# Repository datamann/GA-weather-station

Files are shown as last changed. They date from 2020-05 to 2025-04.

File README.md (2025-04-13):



# Google Assistant based weather station
All documentation about this project is found here:
https://sbsivertsen.atlassian.net/wiki/x/cAPNNg

This project consist of several subprojects:
* Remote Sensors
    - PCB project found here: https://easyeda.com/sbsivertsen/attiny84radiotransmitter
* Base Station
* Cloud Storage
* Google Assistant
* Android & IOS App

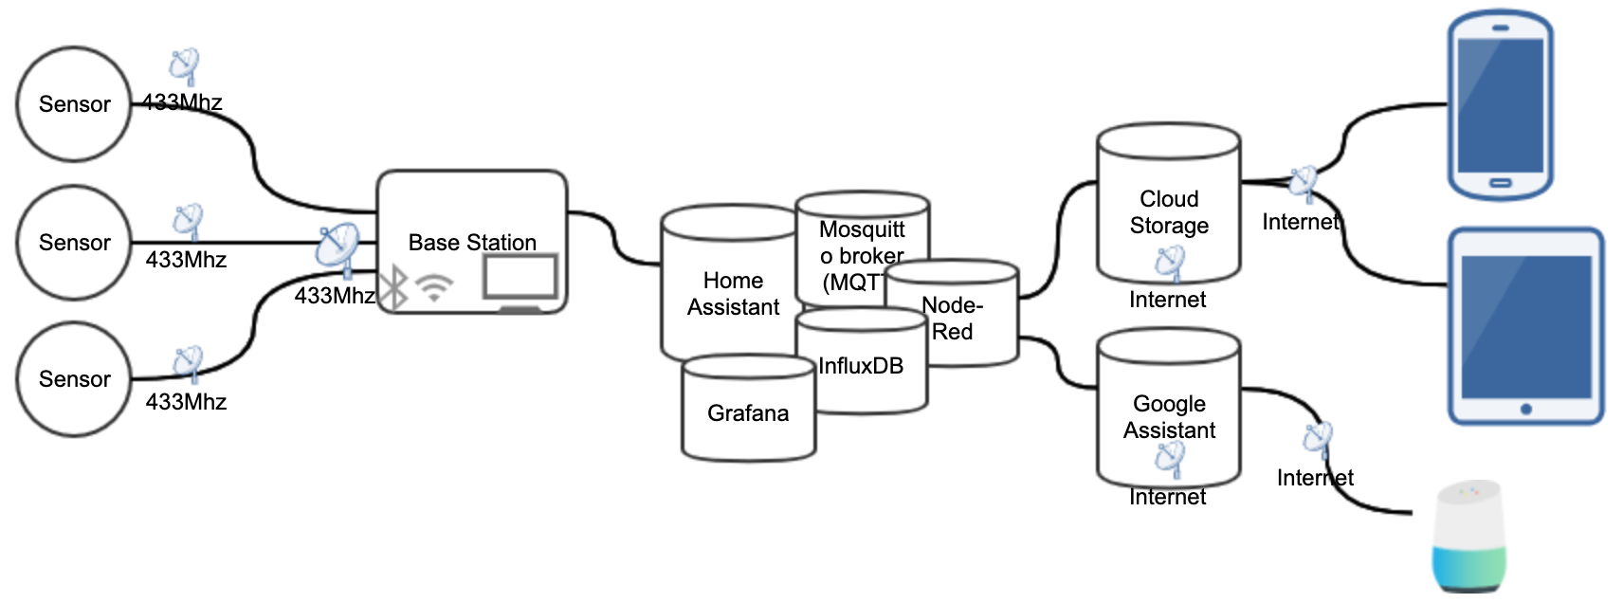
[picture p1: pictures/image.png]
Project architecture


More might come if I feel the need to.

I'm used to create user stories and create tasks from them but as far as I know, I can't do that here in Github.
I will therefor create issues and link them to GIT Projects, labels will also be used to filter issues.

This might change as I learn to use Github.

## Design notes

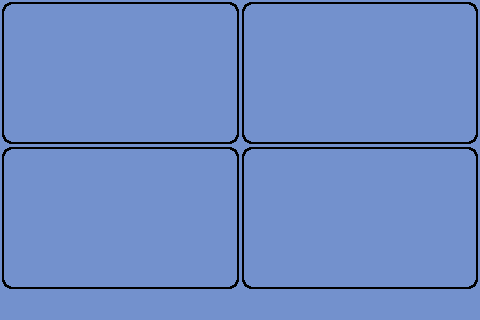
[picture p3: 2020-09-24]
Nextion Project files/images/5DividersWithRoundedCorners.png

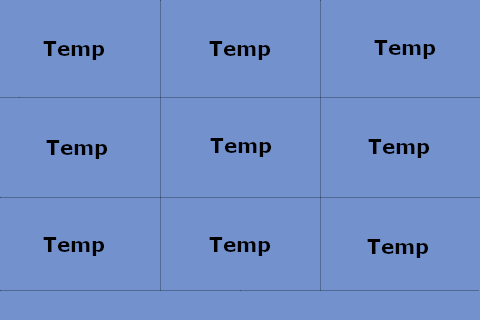
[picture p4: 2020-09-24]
Nextion Project files/images/n.png

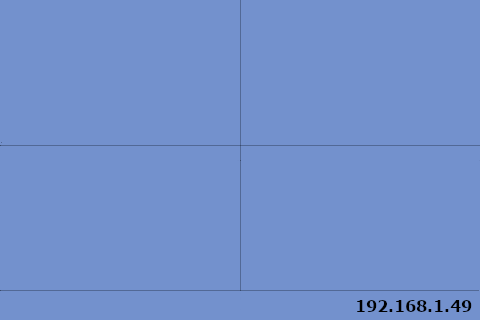
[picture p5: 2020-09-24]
Nextion Project files/images/5DividersWithText.png

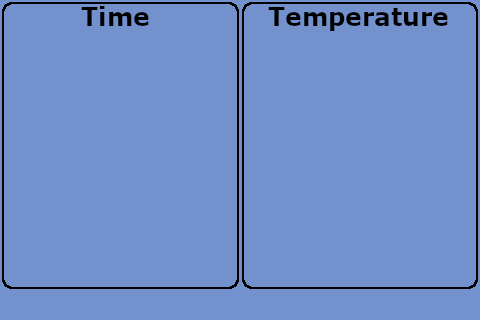
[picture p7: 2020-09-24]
Nextion Project files/images/LocalWeatherPage.png

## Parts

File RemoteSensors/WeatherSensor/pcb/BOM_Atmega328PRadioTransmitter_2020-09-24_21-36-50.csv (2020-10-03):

ID | Name | Designator | Footprint | Quantity | Manufacturer Part | Manufacturer | Supplier | Supplier Part | LCSC Assembly
1 | TJ-S2012SW8TGLC2R-A5 | LED1 | LED0805-R-RD | 1 | TJ-S2012SW8TGLC2R-A5 | TOGIALED | LCSC | C192318
2 | STX882_FLAT | U2 | STX882_FLAT | 1
3 | 2N7002 | Q1 | SOT-23-3_L2.9-W1.3-P1.90-LS2.4-BR | 1 | 2N7002 | JF | LCSC | C501655
4 | 100nF | C1,C3,C6 | C0805 | 3 | 0805B104J250 | Walsin Tech Corp | LCSC | C163184
5 | Atmospheric Sensor Breakout - BME280 | P6 | BME280_6PINS | 1 |  |  |  | 12587
6 | 470nF | C5 | C0805 | 1 | CC0805KKX7R8BB474 | YAGEO | LCSC | C106846
7 | ICSP | P1 | ICSP | 1 | 2.54MM 2*10PDouble row of needle | ReliaPro | LCSC | C62032
8 | CR2032 | B1 | BAT-TH_BS-2-1 | 1 | BS-2-1 | Q&J | LCSC | C70376
9 | ATMEGA328P-AU | U1 | TQFP-32_L7.0-W7.0-P0.80-LS9.0-BL | 1 | ATMEGA328P-AU | MICROCHIP | LCSC | C14877 | Yes
10 | 10uF | C2,C4 | C0805 | 2 | 0805X106K250NT | FH | LCSC | C40894

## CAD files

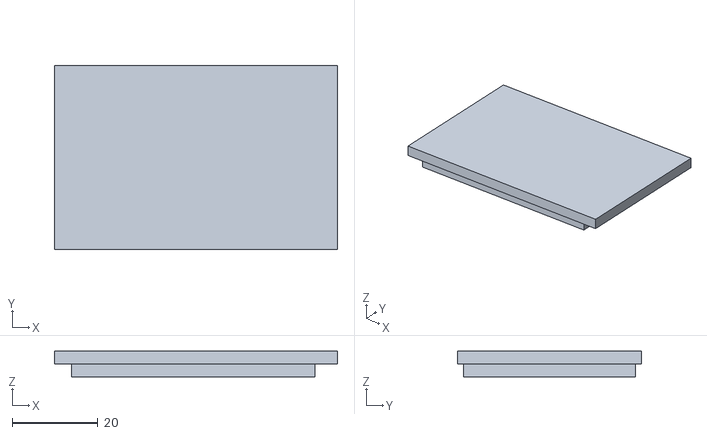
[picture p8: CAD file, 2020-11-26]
STLFiles/Remote Sensor Lid.stl
66.0 x 43.0 x 6.00

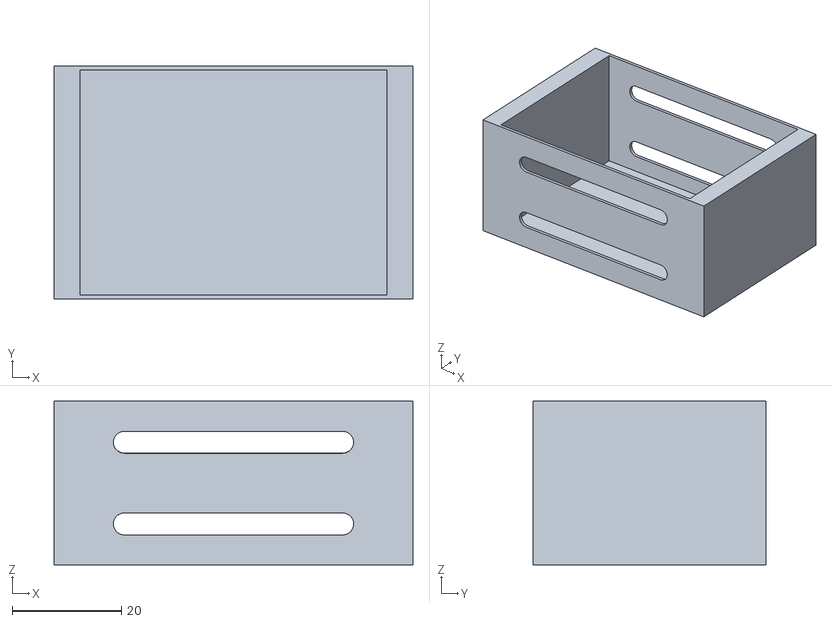
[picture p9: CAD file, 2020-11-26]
STLFiles/Remote Sensor Case v1.stl
65.8 x 42.8 x 30.0

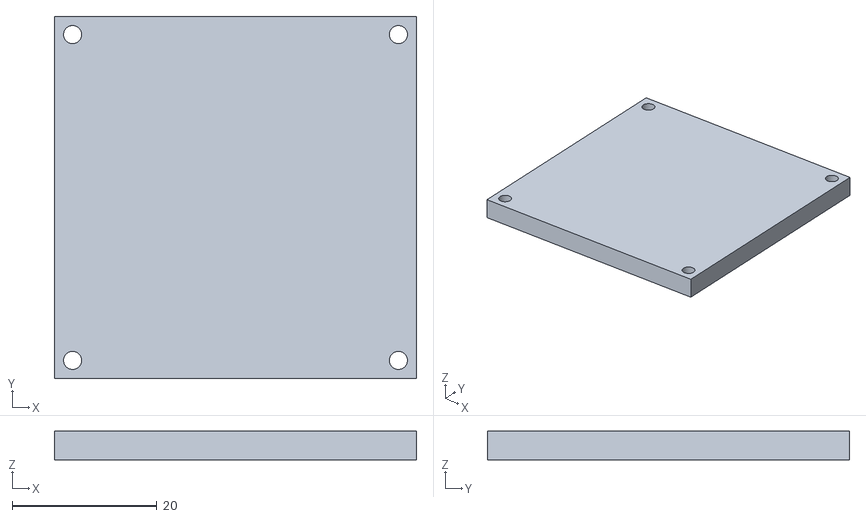
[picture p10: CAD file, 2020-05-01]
STLFiles/EnclosureSensor1.stl
50.0 x 50.0 x 4.00

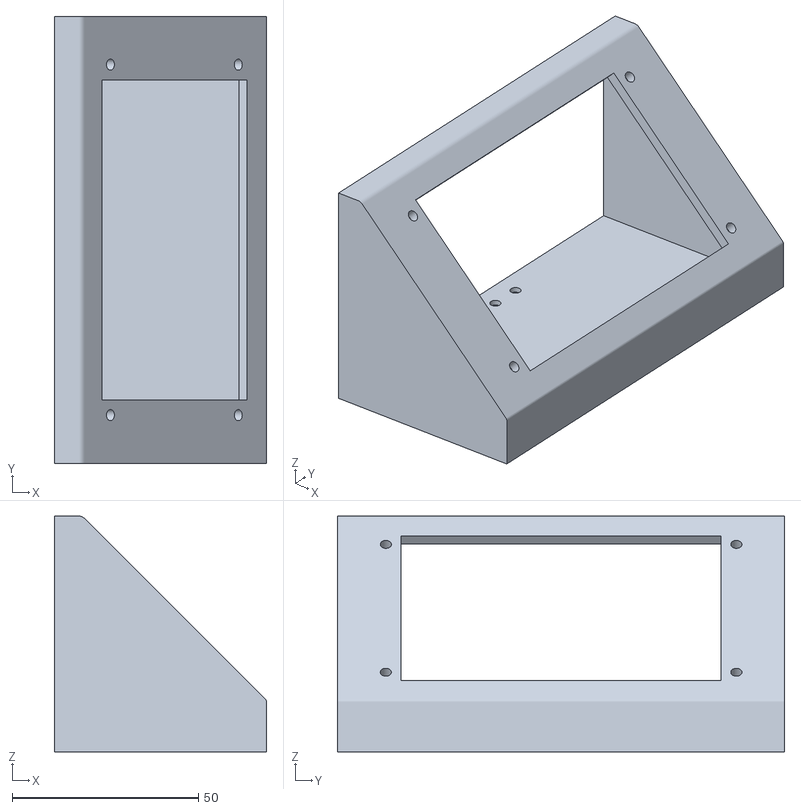
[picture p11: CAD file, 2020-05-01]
STLFiles/EnclosureLCD2.stl
57.0 x 120.0 x 63.3

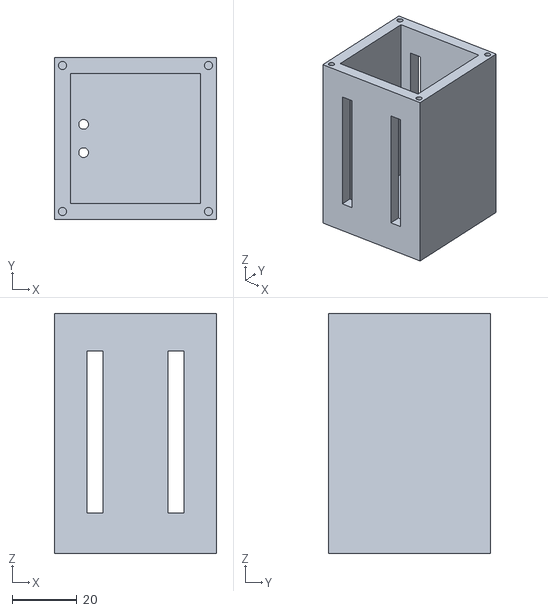
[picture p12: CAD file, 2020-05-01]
STLFiles/EnclosureSensor2.stl
50.0 x 50.0 x 74.0

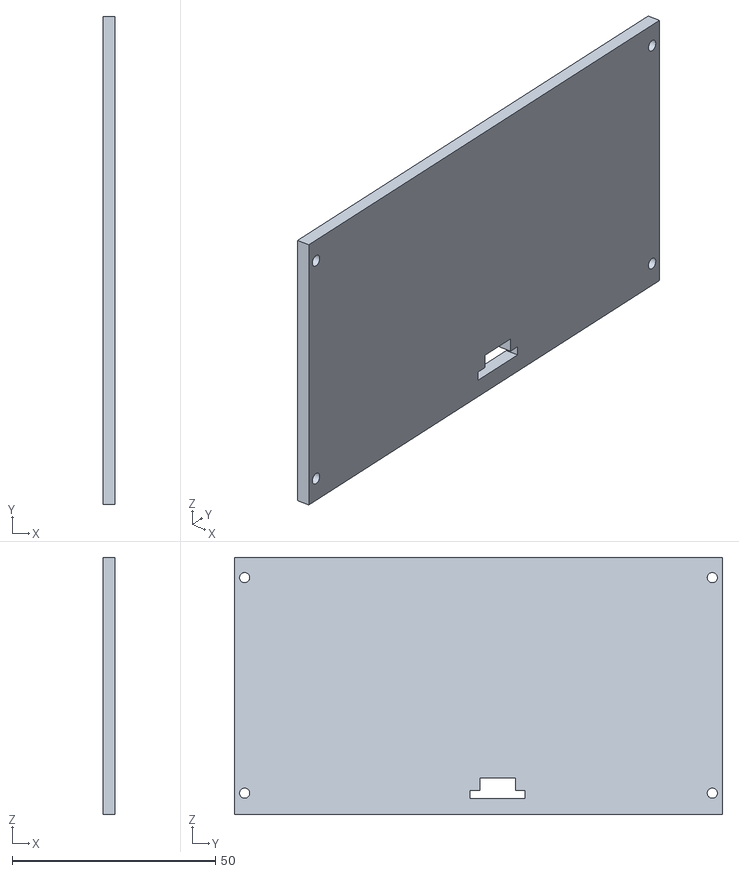
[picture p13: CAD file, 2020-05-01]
STLFiles/EnclosureLCD1.stl
3.00 x 120.0 x 63.3

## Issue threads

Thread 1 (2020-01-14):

Learn to read data from BME 280 using Arduino Nano

datamann, 2020-01-14:
- Learn to read data from BME 280 using Ardunio Nano.

- Find data type and document here: https://aconfluence.no/x/DQD1AQ

- Verify if data can be sent as HEX.

datamann, 2020-01-15:
Datatypes provided from BME280 sensor is float. Documented here:
https://aconfluence.no/x/UAAWAg

datamann, 2020-01-15:
I think it's best to create an struct with float data type and cast it to uint8_t before sending over radio.

datamann, 2020-01-15:
Example:
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

Closed 2020-01-15.

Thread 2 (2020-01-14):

Learn to send BME 280 sensor data using 433MHz ASK Wireless Module kit using Arduino Nano

datamann, 2020-01-14:
- Learn to send BME 280 sensor data using 433MHz ASK Wireless Module kit using Arduino Nano

- Learn to receive sensor data using 433MHz ASK Wireless Module kit using Arduino Nano or ESP32

Closed 2020-01-18.

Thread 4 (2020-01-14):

Learn to send BME 280 sensor data using 433MHz ASK Wireless Module kit using Arduino Nano

datamann, 2020-01-14:
- Learn to send BME 280 sensor data using 433MHz ASK Wireless Module kit using Arduino Nano

- Learn to receive sensor data using 433MHz ASK Wireless Module kit using Arduino Nano or ESP32

Related to #2

Closed 2020-05-02.

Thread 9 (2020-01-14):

Add 433MHz ASK Wireless Module Arduino Nano library to base sketch

datamann, 2020-01-14:
Add 433MHz ASK Wireless Module Arduino Nano library to base sketch

datamann, 2020-04-30:
Library for 433MHz ASK Wireless Module for Arduino Nano added.

Closed 2020-05-02.

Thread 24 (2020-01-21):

Enable battery monitoring

datamann, 2020-01-21:
It should be possible to monitor battery voltage using a voltage divider. This voltage divider shall not consume current while not in use.

Closed 2020-02-06.

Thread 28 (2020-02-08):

Finishing base functions and code tuning

datamann, 2020-02-08:
So far I've testing different functions separately so now it's time to put everything together.
Still on arduino Nano.

Remote Sensor:

- Function to switch off and on BME280 sensor

- Function to read weather data from BME280 sensor

- Added voltage divider to read battery voltage.

- Function to turn on and off voltage divider to prevent current draw while not in use ref. issue #24 .

- Function to send data:
temperature
altitude
pressure
humidity
battery
sensorID

Base Station:

- Changed receiving struct to match Remote Sensor.

- Improved serial print of received data.

Pictures:
https://aconfluence.no/x/vwAWAg

Closed 2020-02-08.

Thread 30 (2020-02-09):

Remote Sensor - Change VREF Delay from 50 to 250

datamann, 2020-02-09:
VREF need at least 2ms delay settle, so this needs to changed in function:
turnOnProbe();
line 94 - from delay(50); to delay(250);

Source: https://www.avrfreaks.net/forum/attiny-adc-using-internal-ref-measure-vcc-problem

Closed 2020-09-24.

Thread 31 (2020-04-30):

Initial working code for Base Station based on ESP32

datamann, 2020-04-30:
Initial code for ESP32 with the following functions:

- Added library for Nextion NX4832T035 Display

- Receiving weather data from remote sensor: Temp, Humidity, Pressure, Altitude, Battery voltage and senor id

- Displaying weather data on LCD

- Added time library to fetch time and date from NTP Server

- Displaying time and date on LCD

- Checking if data is received from remote sensor, if data stop coming in a "Connection lost" warning is displayed on the LCD

Closed 2020-05-02.

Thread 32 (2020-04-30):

Initial working code for Remote Sensor based on Arduino Nano

datamann, 2020-04-30:
Initial code for remote sensor with the following functions:

- Added library for 433Mhx ASK radio module, Radiohead

- Added library for BME280 weather sensor

- Sending weather data: Temp, Humidity, Pressure, Altitude, Battery voltage and senor id

- Reading battery voltage from an voltage divider

- Added power save features like:
Sleep mode for BME280
Sleep mode for voltage probe
Sleep mode for Atmega328

Closed 2020-05-02.

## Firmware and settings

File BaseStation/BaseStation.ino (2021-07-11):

/*
    Written by Stig B. Sivertsen
    sbsivertsen@gmail.com
    https://github.com/datamann/GA-weather-station
    11.07.2021
    @see The GNU Public License (GPL) Version 3
*/

#include <SPI.h>
#include "config.h"

#ifdef ESP32
  #include "esp_bt.h"
#endif

#define DEBUG

// Cities to fetch weather data from
String cityid[] = {"3159016","1711146"}; // Drammen, NO - Ilagan, PH

#include "DisplayData.h"
#include "ntp.h"
#include "rf.h"
#include <ArduinoMqttClient.h>

// Instance of Open Weather Map class
OpenWeatherMap owpDrammen;
OpenWeatherMap owpIlagan;

// Instance of Weather data class
WeatherData ilg;
WeatherData drm;
SensorData sensorData;

// Instance of Display data class
DisplayData dp;


// MQTT Connection
WiFiClient client = init_Wifi();

MqttClient mqttClient(client); // Keepalive is changed in source file (constructor) from 60 to 90 sec.
const char broker[] = "192.168.1.50";
int port = 1883;
const char topicTemperature[]  = "remotesensor/temperature";
const char topicHumidity[]  = "remotesensor/humidity";
const char topicPressure[]  = "remotesensor/pressure";
const char topicBattery[]  = "remotesensor/battery";


void setup() {

  Serial.begin(115200);

  bool rf_connected = init_rf();
  if (!rf_connected) {
    dp.showicon("radioinactive", 1);
    #ifdef DEBUG
      Serial.println();
      Serial.println(F("RF init failed!"));
    #endif
  } else {
    
    dp.showicon("radioinactive", 0);
    dp.showicon("radioactive", 1);
    
    #ifdef DEBUG
      Serial.println(F("RF init succeeded!"));
    #endif
  }

  
  int counter = 0;
  while (WiFi.status() != WL_CONNECTED) {
    dp.showicon("wifiicon", 1);
    delay(200);
    if (++counter > 200) ESP.restart();
    #ifdef DEBUG
      Serial.print (".");
    #endif
  }

  #ifdef ESP32
    // Disable WIFI sleep mode
    if(WiFi.getSleep() == true) {
      WiFi.setSleep(false);
      #ifdef DEBUG
        Serial.println("WiFi Sleep is now deactivated.");
      #endif
    }
  #endif
  
  #ifdef DEBUG
    Serial.print(F("\n\nWiFi connected: "));
    Serial.println(WiFi.localIP().toString());
  #endif

  // If wifi is not connected, show no connection icon
  dp.showicon("wifiicon", 0);

  // You can provide a username and password for authentication
  //mqttClient.setUsernamePassword("sbsivertsen", "j2x83vkf3EDu3W22647e");

  #ifdef DEBUG
    Serial.print("Attempting to connect to the MQTT broker: ");
    Serial.println(broker);
  #endif

  if (!mqttClient.connect(broker, port)) {
    #ifdef DEBUG
      Serial.print("MQTT connection failed! Error code = ");
      Serial.println(mqttClient.connectError());
    #endif
  } else {
    #ifdef DEBUG
      Serial.println("You're connected to the MQTT broker!");
      Serial.println();
    #endif
  }


  // Fetch NTP time and date
  init_ntp();
  getNTPtime(10);
  showTime(timeinfo);
  lastNTPtime = time(&now);
  
  unsigned long lastEntryTime;
  lastEntryTime = millis();
  
  getTime();
  dp.updateDateLCD(td.customDay, td.customDate);
  dp.updateTimeLCD(td.customTime);

  // Fetch weather data for cities
  drm = owpDrammen.fetchWeatherData(cityid[0], apikey, &drm);
  ilg = owpIlagan.fetchWeatherData(cityid[1], apikey, &ilg);

  #ifdef DEBUG
    Serial.print(F("Test"));
    Serial.print(F("Location: "));
    Serial.println(drm.getLocation());
    Serial.print(F("Temperature: "));
    Serial.println(drm.getTemperature());
    Serial.print(F("Feels like: "));
    Serial.println(drm.getFeelslike());
    Serial.print(F("Temp min: "));
    Serial.println(drm.getTemp_min());
    Serial.print(F("Temp max: "));
    Serial.println(drm.getTemp_max());
    Serial.print(F("Pressure: "));
    Serial.println(drm.getPressure());
    Serial.print(F("Humidity: "));
    Serial.println(drm.getHumidity());
    Serial.print(F("Weather: "));
    Serial.println(drm.getWeather());
    Serial.print(F("Description: "));
    Serial.println(drm.getDescription());
    Serial.print(F("Wind speed: "));
    Serial.println(drm.getWindspeed());
    Serial.print(F("Wind direction: "));
    Serial.println(drm.getWinddirection());
    Serial.print(F("Wind compass direction: "));
    Serial.println(drm.getWindcompassdirection());
    Serial.print(F("Weather ID: "));
    Serial.println(drm.getWeatherid());
    Serial.println(F(" "));
    Serial.print(F("Location: "));
    Serial.println(ilg.getLocation());
    Serial.print(F("Temperature: "));
    Serial.println(ilg.getTemperature());
    Serial.print(F("Feels like: "));
    Serial.println(ilg.getFeelslike());
    Serial.print(F("Temp min: "));
    Serial.println(ilg.getTemp_min());
    Serial.print(F("Temp max: "));
    Serial.println(ilg.getTemp_max());
    Serial.print(F("Pressure: "));
    Serial.println(ilg.getPressure());
    Serial.print(F("Humidity: "));
    Serial.println(ilg.getHumidity());
    Serial.print(F("Weather: "));
    Serial.println(ilg.getWeather());
    Serial.print(F("Description: "));
    Serial.println(ilg.getDescription());
    Serial.print(F("Wind speed: "));
    Serial.println(ilg.getWindspeed());
    Serial.print(F("Wind direction: "));
    Serial.println(ilg.getWinddirection());
    Serial.print(F("Wind compass direction: "));
    Serial.println(ilg.getWindcompassdirection());
    Serial.print(F("Weather ID: "));
    Serial.println(ilg.getWeatherid());
    Serial.println();
  #endif
}

// Variables to support auto time update
bool timeChanged = true;
bool hourChanged = true;
bool dateChanged = true;
String compareTime;
String compareHour;
String compareDate;

// Variables to support auto page rotation
bool page0Turned = true;
bool page1Turned = false;
bool page2Turned = false;
const unsigned long turnPageInterval = 60UL*1000UL; // How fast the screen pages rotate
unsigned long previousTurnPageTime = 0;

// Variables to support RF connection loss
const unsigned long wait_for_connection = 180000; // 30 sec in ms, after 30sec, conneciton loss alarm!
unsigned long connection_lost;
bool timerSet = false;

/************************************* LOOP ************************************************************/

void loop() {

  // Display icon on LCD if RF connection is lost
  unsigned long now = millis();
  if (now - connection_lost >= wait_for_connection)
  {
    dp.showicon("radioinactive", 1);
  }
  else
  {
    dp.showicon("radioinactive", 0);
  }

  // RF Receive
  uint8_t data[RH_ASK_MAX_MESSAGE_LEN];
  uint8_t len = sizeof(data);

  // Checking if RF connection is up and running
  now = millis();

  if (!rf.available())
  {
    if (!timerSet)
    {
      connection_lost = now;
    }
    timerSet = true;
  }
  else
  {
    timerSet = false;
    dp.showicon("radioactive", 1);

    // Receive data from remote sensor
    if (rf.recv(data, &len)) {
      rfwd* weatherdata = (rfwd*)data;


      // Filling Sensor data class with data from the remote sensor
      sensorData.setTemperature(weatherdata->temperature);
      sensorData.setPressure(weatherdata->pressure);
      sensorData.setHumidity(weatherdata->humidity);
      sensorData.setBattery(weatherdata->battery);
      sensorData.setSensorid(weatherdata->sensorID);

      // Displaying remote sensor data on LCD
      dp.showicon("radioinactive", 0);
      dp.printToLCD("location0.txt", "Verven 30");
      dp.printToLCD("temperature0.txt", String(sensorData.getTemperature()));
      dp.printToLCD("humidity0.txt", String(sensorData.getHumidity()));
      dp.printToLCD("pressure0.txt", String(sensorData.getPressure()));
      dp.printToLCD("battery.txt", String(sensorData.getBattery()));
      dp.showicon("radioactive", 0);


      if (!mqttClient.connect(broker, port)) {
        #ifdef DEBUG
          Serial.print("MQTT connection failed! Error code = ");
          Serial.println(mqttClient.connectError());
        #endif
      } else {
        #ifdef DEBUG
          Serial.println("You're connected to the MQTT broker!");
          Serial.println();
        #endif
      }

      // Sending data to MQTT Broker
      mqttClient.beginMessage(topicTemperature);
      mqttClient.print(sensorData.getTemperature());
      mqttClient.endMessage();

      mqttClient.beginMessage(topicHumidity);
      mqttClient.print(sensorData.getHumidity());
      mqttClient.endMessage();

      mqttClient.beginMessage(topicPressure);
      mqttClient.print(sensorData.getPressure());
      mqttClient.endMessage();
      
      mqttClient.beginMessage(topicBattery);
      mqttClient.print(sensorData.getBattery());
      mqttClient.endMessage();

      #ifdef DEBUG
        Serial.print(F("Temperature: "));
        Serial.print(sensorData.getTemperature());
        Serial.println(F("c"));
        Serial.print(F("Pressure: "));
        Serial.print(sensorData.getPressure());
        Serial.println(F("hpa"));
        Serial.print(F("Humidity: "));
        Serial.print(sensorData.getHumidity());
        Serial.println(F("%"));
        Serial.print(F("Battery: "));
        Serial.print(sensorData.getBattery());
        Serial.println(F("v"));
        Serial.print(F("Sensor ID: "));
        Serial.println(sensorData.getSensorid());
        Serial.println();
      #endif

    }
   }


  // Fetches NTP time and updates the LCD when time and date have changed
  getNTPtime(1000);
  getTime();

  // Auto screen rotation
  unsigned long currentTurnPageTime = millis();
  if (currentTurnPageTime - previousTurnPageTime >= turnPageInterval) {
    
    if(page0Turned){
      dp.turnPage(cityid, "1", td.customTime, td.customDay, td.customDate, ilg, drm, sensorData, WiFi.localIP().toString());
      page0Turned = false;
      page1Turned = true;
    }else if(page1Turned){
      dp.turnPage(cityid, "2", td.customTime, td.customDay, td.customDate, ilg, drm, sensorData, WiFi.localIP().toString());
      page1Turned = false;
      page2Turned = true;
    }else if(page2Turned){
      dp.turnPage(cityid, "0", td.customTime, td.customDay, td.customDate, ilg, drm, sensorData, WiFi.localIP().toString());
      page2Turned = false;
      page0Turned = true;
    }
    previousTurnPageTime += turnPageInterval;
  }

  // Update screen data when screen button is pressed
  dp.readLCDData(cityid, td.customDay, td.customDate, td.customTime, ilg, drm, sensorData, WiFi.localIP().toString());

  // Updating time and date only when time or date has changed

  // Checking if hours has changed
  String oldHour = td.customHour;
  if (hourChanged){
    compareHour = oldHour;
    hourChanged = false;
  }
  
  if (compareHour != oldHour)
  {
    drm = owpDrammen.fetchWeatherData(cityid[0], apikey, &drm);
    ilg = owpIlagan.fetchWeatherData(cityid[1], apikey, &ilg);
    #ifdef DEBUG
      Serial.print(F("Hour: "));
      Serial.println(td.customHour);
    #endif
    
    hourChanged = true;
  }

  // Cheking if time has changed
  String oldTime = td.customTime;
  if (timeChanged)
  {
    compareTime = oldTime;
    timeChanged = false;
  }

  if (compareTime != oldTime)
  {
    dp.updateTimeLCD(td.customTime);
    #ifdef DEBUG
      Serial.print(F("Time: "));
      Serial.println(td.customTime);
    #endif
    
    timeChanged = true;
    mqttClient.poll(); // Polling MQTT Server once every minute.
  }

  // Checking if date has changed
  String oldDate = String(td.customDate);
  if (dateChanged)
  {
    compareDate = oldDate;
    dateChanged = false;
  }

  if (compareDate != oldDate)
  {
    dp.updateDateLCD(td.customDay, td.customDate);
    #ifdef DEBUG
      Serial.print(F("Day: "));
      Serial.println(td.customDay);
      Serial.print(F("Date: "));
      Serial.println(td.customDate);
    #endif
    
    dateChanged = true;
  }
}

// NOT IN USE YET
// TODO: Implement remote sensor "feels like" temperature.
float convertFtoC(float f) { return (f - 32) * 0.55555; }

/*!
 *  @brief  Compute Heat Index
 *          Using both Rothfusz and Steadman's equations
 *          (http://www.wpc.ncep.noaa.gov/html/heatindex_equation.shtml)
 *  @param  temperature
 *          temperature in selected scale
 *  @param  percentHumidity
 *          humidity in percent
 *  @param  isFahrenheit
 *          true if fahrenheit, false if celcius
 *  @return float heat index
 *  @source https://github.com/adafruit/DHT-sensor-library/blob/master/DHT.cpp
 */
float computeHeatIndex(float temperature, float percentHumidity, bool isFahrenheit) {
  float hi;

  hi = 0.5 * (temperature + 61.0 + ((temperature - 68.0) * 1.2) +
              (percentHumidity * 0.094));

  if (hi > 79) {
    hi = -42.379 + 2.04901523 * temperature + 10.14333127 * percentHumidity +
         -0.22475541 * temperature * percentHumidity +
         -0.00683783 * pow(temperature, 2) +
         -0.05481717 * pow(percentHumidity, 2) +
         0.00122874 * pow(temperature, 2) * percentHumidity +
         0.00085282 * temperature * pow(percentHumidity, 2) +
         -0.00000199 * pow(temperature, 2) * pow(percentHumidity, 2);

    if ((percentHumidity < 13) && (temperature >= 80.0) &&
        (temperature <= 112.0))
      hi -= ((13.0 - percentHumidity) * 0.25) *
            sqrt((17.0 - abs(temperature - 95.0)) * 0.05882);

    else if ((percentHumidity > 85.0) && (temperature >= 80.0) &&
             (temperature <= 87.0))
      hi += ((percentHumidity - 85.0) * 0.1) * ((87.0 - temperature) * 0.2);
  }

  return isFahrenheit ? hi : convertFtoC(hi);
}

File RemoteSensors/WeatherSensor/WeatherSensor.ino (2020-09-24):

/***************************************************************************
  This is a library for the BME280 humidity, temperature & pressure sensor

  Designed specifically to work with the Adafruit BME280 Breakout
  ----> http://www.adafruit.com/products/2650

  These sensors use I2C or SPI to communicate, 2 or 4 pins are required
  to interface. The device's I2C address is either 0x76 or 0x77.

  Adafruit invests time and resources providing this open source code,
  please support Adafruit andopen-source hardware by purchasing products
  from Adafruit!

  Written by Limor Fried & Kevin Townsend for Adafruit Industries.
  BSD license, all text above must be included in any redistribution
  See the LICENSE file for details.
 ***************************************************************************/

 /*
 * Written by Stig B. Sivertsen
 * sbsivertsen@gmail.com
 * https://github.com/datamann/GA-weather-station
 * 21.09.2020
 * @see The GNU Public License (GPL) Version 3
*/

#include <avr/sleep.h>
#include <avr/wdt.h>
#include <avr/power.h>
#include <Wire.h>
#include <SPI.h>
#include <Adafruit_Sensor.h>
#include <Adafruit_BME280.h>
#include <RH_ASK.h>

int nbr_remaining;
int sleep_time = 19; // 19 = 2.5min

ISR(WDT_vect)
{
  wdt_reset();
}

// Comment out to turn off debug
//#define DEBUG

#define SEALEVELPRESSURE_HPA (1013.25) // Default sea level pressure

Adafruit_BME280 bme;
RH_ASK rf(2000, -0,10); // 2000bps, RX=0, TX=D10 - Transmitt only

unsigned long delayTime;

struct wd {
  float temperature;
  float altitude;
  float pressure;
  float humidity;
  float battery;
  uint8_t sensorID = 1;
  //time_t timeStamp;   // For future use
}; wd weatherdata;

void configure_wdt(void) {
  cli();
  MCUSR = 0;
  WDTCSR |= 0b00011000;
  WDTCSR =  0b01000000 | 0b100001;
  sei();

  /*cli();
  WDTCSR = (24);//change enable and WDE - also resets
  WDTCSR = (33);//prescalers only - get rid of the WDE and WDCE bit
  WDTCSR |= (1<<6);//enable interrupt mode
  sei();*/
}

// Put the Arduino to deep sleep. Only an interrupt can wake it up.
void sleep(int ncycles)
{  
  nbr_remaining = ncycles;
  set_sleep_mode(SLEEP_MODE_PWR_DOWN);
  
  //power_adc_disable();
  ADCSRA &= ~(1 << 7);
 
  while (nbr_remaining > 0) {
    sleep_mode();
    sleep_disable();
    nbr_remaining = nbr_remaining - 1;
  }
  power_all_enable();
}

void setup() {
    configure_wdt();

    for (int i = 0; i < 20; i++) {
      pinMode(i, OUTPUT);
    }
    
    analogReference(INTERNAL);
    analogRead(A0);
    
    Serial.begin(9600);
    
    while(!Serial);
        #ifdef DEBUG
            Serial.println(F("BME280 running"));
        #endif

    unsigned status;
    status = bme.begin(0x76);
    
    if (!status) {
        #ifdef DEBUG
            Serial.println(F("Could not find a valid BME280 sensor, check wiring, address, sensor ID!"));
            Serial.print(F("SensorID was: 0x"));
            Serial.println(bme.sensorID(),16);
            Serial.print(F("        ID of 0xFF probably means a bad address, a BMP 180 or BMP 085\n"));
            while (1) delay(10);
        #endif
    }

    delayTime = 1000;
    if (!rf.init())
    {
        #ifdef DEBUG
            Serial.println(F("RF init failed"));
        #endif
    }

  // Blinking LED to indicate that the Remote Sensor is alive.
  for (int i = 0; i < 6; i++) {
    digitalWrite(2, HIGH);
    delay(50);
    digitalWrite(2, LOW);
    delay(50);
  }
}

void turnOnBME280(){
    bme.setSampling(Adafruit_BME280::MODE_NORMAL);
    delay(50);
}

void turnOffBME280(){
    bme.setSampling(Adafruit_BME280::MODE_SLEEP);
    delay(50);
}

float getBatteryVolts() {
  // http://www.gammon.com.au/adc
  // https://github.com/RalphBacon/Arduino-Battery-Monitor

  // You MUST measure the voltage at pin 21 (AREF) using just a simple one line sketch consisting
  // of:  analogReference(INTERNAL);
  //      analogRead(A0);
  // Then use the measured value here.

  const float InternalReferenceVoltage = 1.096; // <- as measured (or 1v1 by default)

  // turn ADC on
  ADCSRA =  bit (ADEN);

  // Prescaler of 128
  ADCSRA |= bit (ADPS0) |  bit (ADPS1) | bit (ADPS2);

  // MUX3 MUX2 MUX1 MUX0  --> 1110 1.1V (VBG) - Selects channel 14, bandgap voltage, to measure
  ADMUX = bit (REFS0) | bit (MUX3) | bit (MUX2) | bit (MUX1);

  // let it stabilize
  delay (50);

  // start a conversion
  bitSet (ADCSRA, ADSC);

  // Wait for the conversion to finish
  while (bit_is_set(ADCSRA, ADSC))
  {
    ;
  }

  // Float normally reduces precion but works OK here. Add 0.5 for rounding not truncating.
  float results = InternalReferenceVoltage / float (ADC + 0.5) * 1024.0;
  ADMUX =~ bit (REFS0) | bit (MUX3) | bit (MUX2) | bit (MUX1);
  return results;
}

void sendPacket(){
    rf.send((uint8_t *)&weatherdata, sizeof(weatherdata));
    rf.waitPacketSent();
}

void readWeatherData(){
    
    weatherdata.temperature = 0;
    weatherdata.pressure = 0;
    weatherdata.altitude = 0;
    weatherdata.humidity = 0;
    weatherdata.battery = 0;
    
    weatherdata.temperature = bme.readTemperature();
    weatherdata.pressure = bme.readPressure() / 100.0F;
    weatherdata.altitude = bme.readAltitude(SEALEVELPRESSURE_HPA);
    weatherdata.humidity = bme.readHumidity();
}

void loop() {

    Serial.println(F("Waking up..."));
    
    turnOnBME280();
    readWeatherData();
    turnOffBME280();
    weatherdata.battery = getBatteryVolts();
    printValues();
    sendPacket();

    Serial.println(F("Going to sleep..."));
    delay(20);
    sleep(sleep_time);
}

void printValues() {

    #ifdef DEBUG
        char buf[31];
      
        char temperature[7];
        char pressure[6];
        char altitude[5];
        char humidity[6];
        char batt[5];
        char id[2];
      
        dtostrf(weatherdata.temperature, 3, 2, temperature);
        dtostrf(weatherdata.pressure, 4, 0, pressure);
        dtostrf(weatherdata.altitude, 4, 0, altitude);
        dtostrf(weatherdata.humidity, 3, 0, humidity);
        dtostrf(weatherdata.battery, 1, 2, batt);
        dtostrf(weatherdata.sensorID, 1, 0, id);
      
        sprintf(buf,"%s %s %s %s %s %s", temperature, pressure, altitude, humidity, batt, id);
        Serial.print(F("Buf: "));
        Serial.println(buf);
    #endif
}

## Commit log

2020-01-15 Added Arduino base sketch
2020-01-15 Added Arduino libraries
2020-01-18 Created base ESP32 sketch for Base Station and added 433MHz ASK Wireless Module library
2020-01-18 Learn to send BME 280 sensor data using 433MHz ASK Wireless Module kit using Arduino Nano, Did code cleanup and code formatting
2020-02-06 Added pin controlled battery monitoring
2020-02-06 Trying to fix wrong use of git
    [WeatherSensor.ino]
2020-02-08 Finishing base functions and code tuning. Fixes #28
    [BaseStation.ino, WeatherSensor.ino]
2020-05-01 Initial working code for base station and resmote sensor. Added library files.
    [EnclosureLCD1.stl, EnclosureLCD2.stl, EnclosureSensor1.stl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]
2020-10-03 Added RemoteSensor PCB and updated README
    [BOM_Atmega328PRadioTransmitter_2020-09-24_21-36-50.csv, PickAndPlace_Transmitter_2020-09-24_22-12-36.csv]
2020-11-26 Added remote sensor case
    [Remote Sensor Case v1.stl, Remote Sensor Lid.stl]
